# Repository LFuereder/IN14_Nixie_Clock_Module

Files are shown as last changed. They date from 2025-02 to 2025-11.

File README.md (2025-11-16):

# IN14-Nixie Tube Clock Module
This project contains the schematics, software implementation and documentation for a clock displaying the current time on nixie-tubes. The clock utilizes a GigaDevices GD32L233 microcontroller (ARM Cortex-M33), which triggers the displayed digits in the tubes via voltage-domain separation through LTV-352T optocouplers. 

The current design is planned to display hours and minutes, but it can be extended to display the seconds as well. 

The general structure of the project is as follows:
```
IN14_Nixie_Clock_Module/
|-- 01_Circuit_Board/
|-- 02_Software/
|-- 03_Datasheets/
```
In the folder `01_Circuit_Board` you can find all relevant files for the hardware part of this project. This includes the KiCAD project, footprints for the custom components and the CAD script for the custom tube socket. In folder `02_Software` you can find the implementation of the clock. As this is a module, the Board can be used as standalone application (although this does not make much sense, since you need at least two PCBs to display the current time) or as a set of two to display hour and minutes. A clock consisting of three boards is currently not supported, but can be extended in the future. Lastly in `03_Datasheets` you can find further information about the components in use. 

# Finished Prototype
The current prototype of a finished implementation of the clock is displayed in the figure below.

<p align="center">
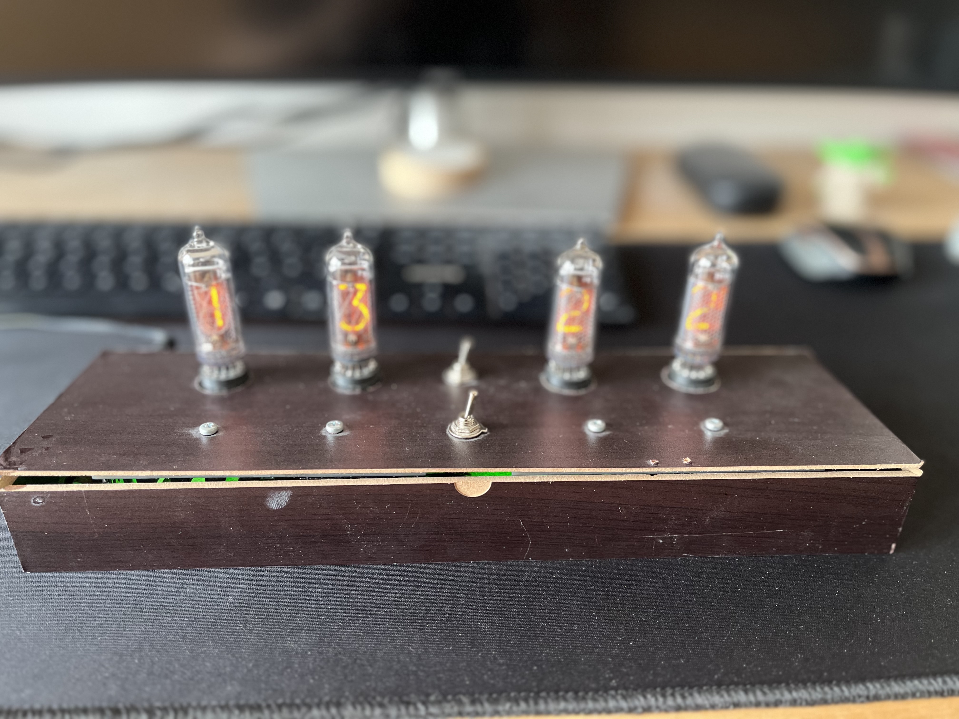
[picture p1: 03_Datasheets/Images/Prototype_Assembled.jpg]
Assembled prototype of the IN-14 nixie tube clock

</p>

For the wiring between the modules and the DCDC-converter please consider the following image:

<p align="center">
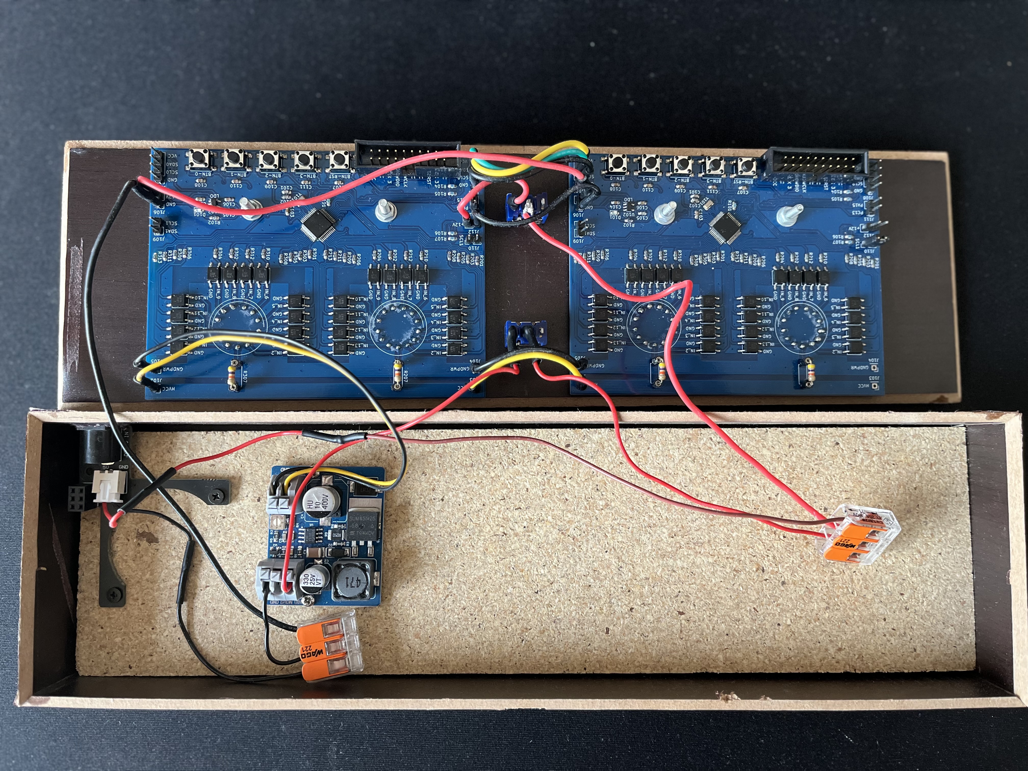
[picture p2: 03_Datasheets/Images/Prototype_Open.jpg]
Internal wiring of the IN-14 nixie tube clock prototype

</p>

Since this is a prototype, we used dupont crimp connectors and wago cage clamps. In a finished product these could be replaced by fixed/soldered wires.

# Contributing
I would like to thank [@LStromaier](https://github.com/LStrohmaier) for working along side me on this project and reviewing most of the hardware and software implemenatations.

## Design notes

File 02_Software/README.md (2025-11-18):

# Software Design
The software implementation for the nixie clock utilizes the [Firmware Library](https://www.gd32mcu.com/en/download/7?kw=GD32L2) and  SVD-file (`GD32L23x.svd`) avaiable at the GigaDevices website. Furthermore, the repository contains a simple custom linker-script (`GD32L2xx.ld`), startup code (`GD32:startup.c`) for the GD32L2xx microcontroller.

The structure of the `02_Software` folder is as follows:
```
02_Software/
|-- .vscode/
|-- CMSIS/
|-- inc/
|-- lib/
|-- src/
|-- <startup-code, linker script and SVD-file>
```
The Visual Studio Code (VS-Code) specific configuration files are located in the `.vscode` folder and currently contain the default install paths for compiler and debugger on Linux (Debian). Do feel free to adjust them to your own setup. The Gigadevices firmware library mentioned above is integrated into the project in the ARM Common Microcontroller Software Interface Standard (CMSIS) implementation in the  `CMSIS` folder and Hardware Abstraction Layer (HAL) for the GD32L2xx microcontroller in the `lib` folder. 

The implementation for the main routine and ISRs is located in the `inc` (header files) and `src` (source files) as typically done in embedded C. 

## Getting started
In order to build the code, please install the following prerequisites on your PC. Depending on the corresponding operating system, the installation method might differ from the one explained here. On Linux (Debian) execute the follwoing command in a terminal window:
```sh
sudo apt update \
sudo apt install make arm-none-eabi-gcc gdb
```

Subsequently navigate to the `02_Sofware` folder of the repository and create a build folder by executing the following command:
```sh
mkdir build
```

Lastly, build the application by typing the following command in the terminal.
```sh
make all
```

If everything works correctly, the build successful promt should appear in the terminal window.

For cleaning up or rebuilding the software, the `Makefile` also supports the commands **make new** and **make clean**. 

## Flashing and Debugging
For flashing and debugging we utilize a [J-Link](https://www.segger.com/products/debug-probes/j-link/) debug probe. The necessary software for this debugger can be downloaded from the companies website. 

In combination with the cortex-debug plugin in Visual Studio Code, we can directly flash and program the microcontroller. For further information, please refer to the `launch.json` and `c_cpp_properties.json` files in the `.vscode/` subfolder.  

## Design Concept
The software design is intended to be as simple as possible and provide the clock configuration asynchronously through interrupt service routines, while the display of the current time is managed in the main routine.

<p align="center">
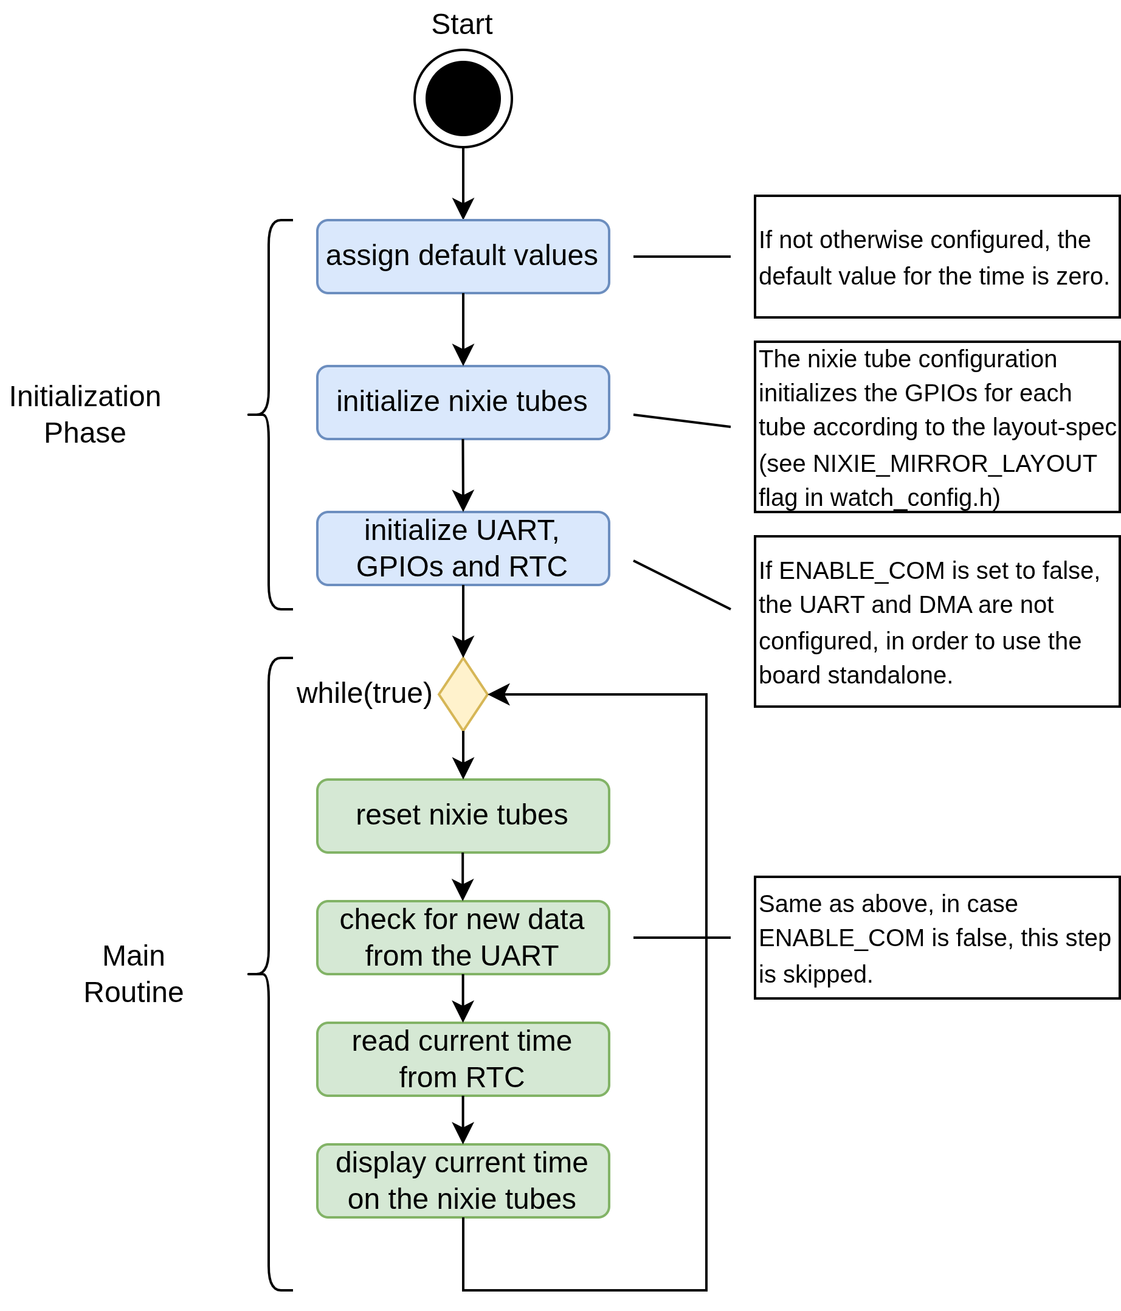
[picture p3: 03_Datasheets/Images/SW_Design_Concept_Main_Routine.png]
Internal wiring of the IN-14 nixie tube clock prototype

</p>

As displayed in the figure above, the main routine implementation first initializes all peripherals and after that periodically polls the RTC, as well as the UART implementation for new values to display. 

### Clock Configuration
Through pushing buttons BTN-3 to BTN-0, the current time can be set in the watch. The implementation for this works as follows.

<p align="center">
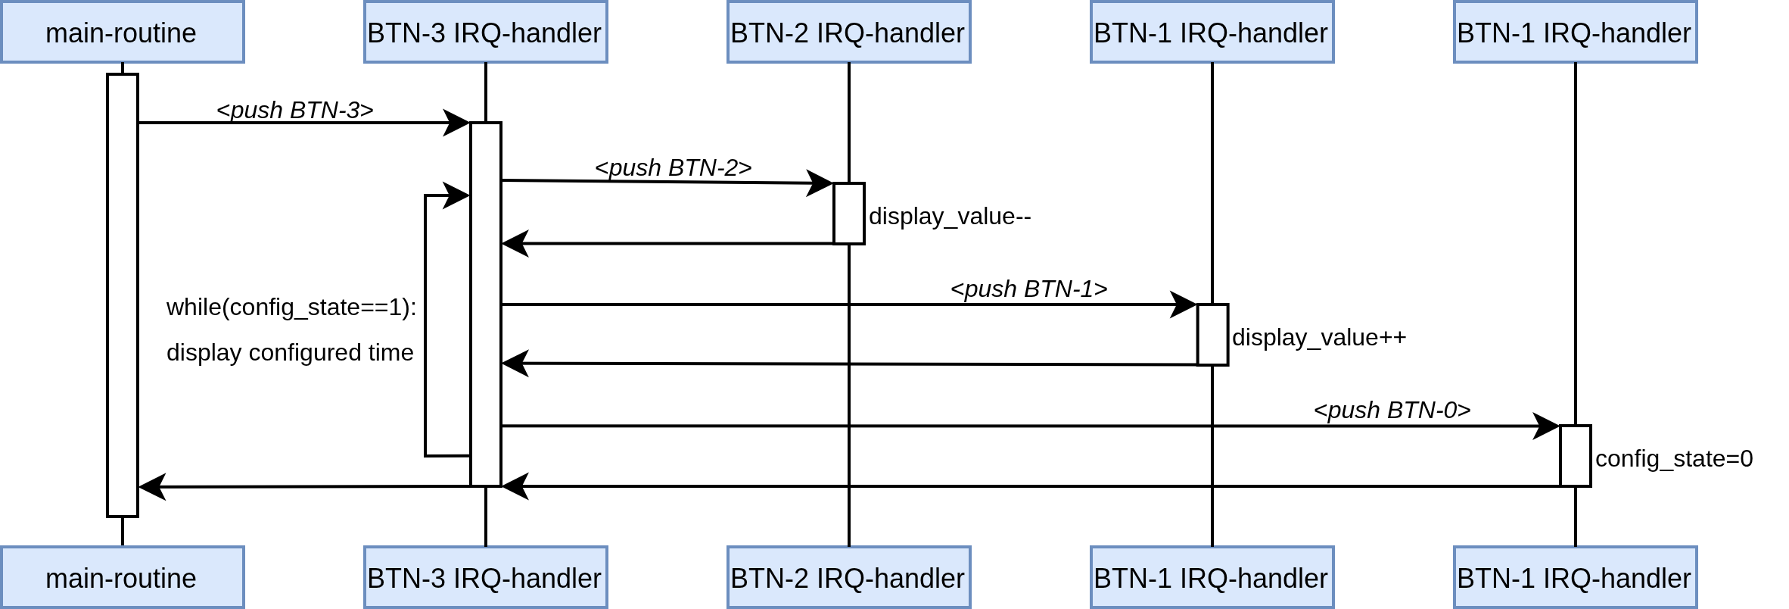
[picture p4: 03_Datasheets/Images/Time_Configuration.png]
Configuration steps for setting the time in the clock

</p>

As displayed in the figure above, the nixie-clock switches into the configuration mode by pushing button 3. In this IRQ-routine the config_state flag is set to 1 and iterates over a display of the current configuration value until button 0 is pressed to reset the config_state flag back to 0 and terminate the configuration mode. 

Buttons 2 and 3 can be used to increase or decrease the currently displayed value of the nixie-tube module. By bridging the Jumper `J111` on the PCB before start-up, the implementation can be set to display the current minutes, otherwise it displays the current hours.

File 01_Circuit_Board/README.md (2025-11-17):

# Hardware Design
The Printed Circuit Board (PCB) was designed in KiCAD as a two layer board with a separation of the voltage domain for the nixie tubes (HVCC=200V) and the board input voltage (VCC=12V). The finished PCB is displayed in the figure below:

<p align="center">
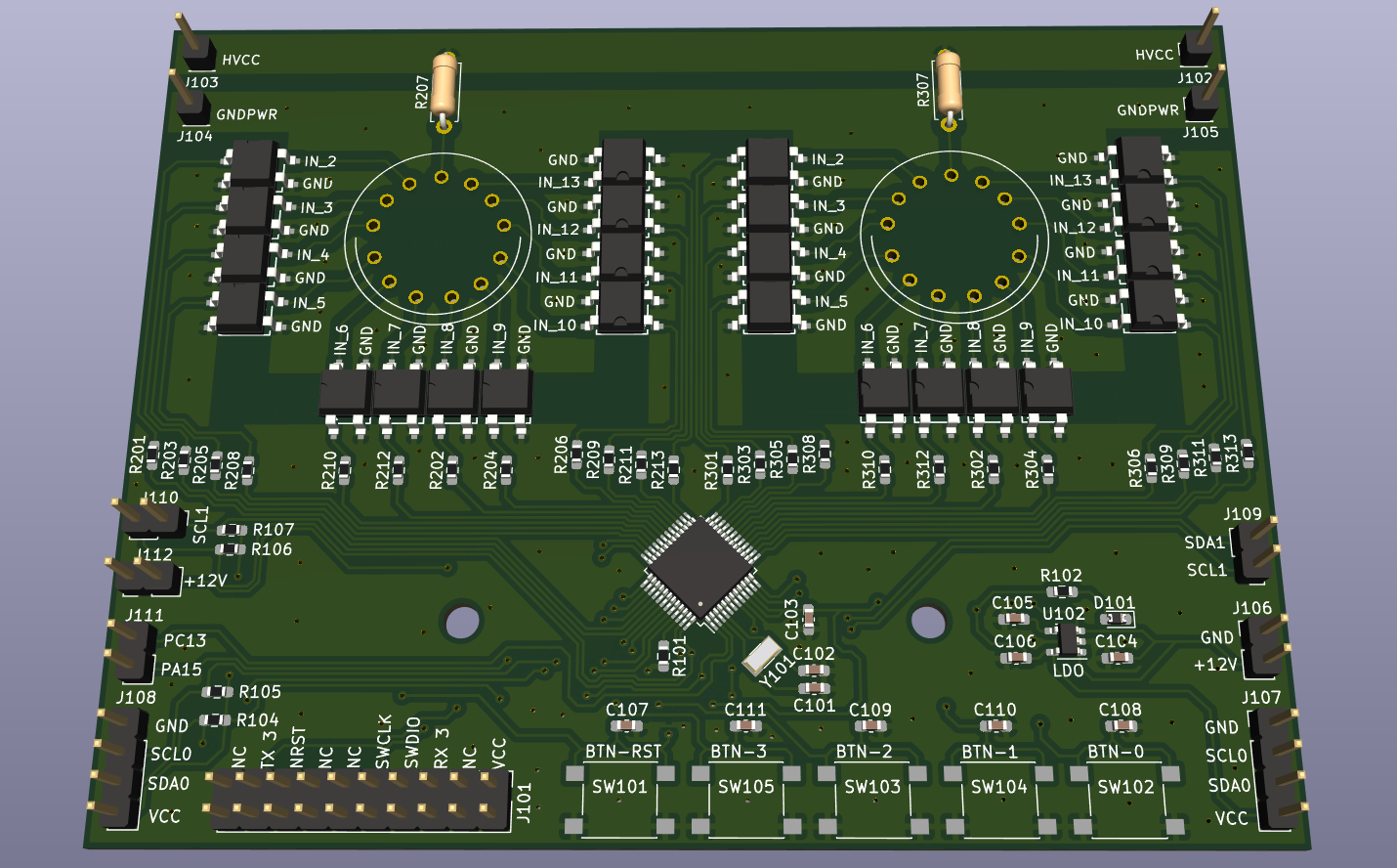
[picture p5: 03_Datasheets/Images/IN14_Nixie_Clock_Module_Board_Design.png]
Internal wiring of the IN-14 nixie tube clock prototype

</p>

Currently the power-supply is not contained in the board design and provided through an external DCDC-converter. A similar one can be used as the on sold [here](https://www.amazon.de/dp/B07H4L5NHG). 

The structure of the `01_Circuit_Board/` folder is as follows:
```
01_Circuit_Board/
    |-- bom/
    |-- footprints.pretty/
    |-- socket/
    |-- <KiCAD-Project files>
```
The following paragraphs explain briefly the content of each subfolder. 

# Componentes
In the subfolder `bom/` you can find the Bill of Materials (BOM), which contains all components and the correstponding positions on the PCB used in this project. The BOM is displayed as a simple HTML file, which you can open in your prefered web-browser simply by clicking [here](./01_Circuit_Board/bom/BOM_aurol_IN14_01.html). 

# Custom Footprints
The footprints located in the subfolder `footprints.pretty/` (default name in KiCAD) are used for the optocouplers, the custom IN-14 nixie-tube sockets. 

# Nixie-Tube Socket
In order to provide a universal socket for the IN-14 nixie-tubes, the subfolder `socket/` contains an openSCAD script, as well as the STL file for the 3D printable socket. In combination with [female connector pins](https://www.amazon.de/dp/B0C1GNPGRV) the socket can be assembled as a through-hole component, which can be soldered on the PCB.

# License
Please consider, that the entire Kicad Project is licensed unter the Apache 2.0 License

Copyright 2025 Lukas Füreder

Licensed under the Apache License, Version 2.0 (the "License");
you may not use this file except in compliance with the License.
You may obtain a copy of the License at

       http://www.apache.org/licenses/LICENSE-2.0

Unless required by applicable law or agreed to in writing, software
distributed under the License is distributed on an "AS IS" BASIS,
WITHOUT WARRANTIES OR CONDITIONS OF ANY KIND, either express or implied.
See the License for the specific language governing permissions and
limitations under the License.

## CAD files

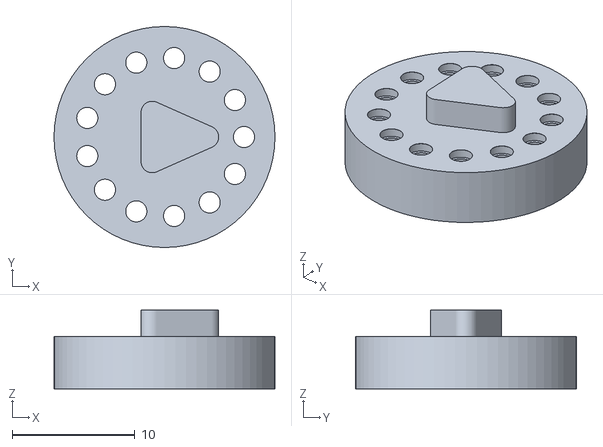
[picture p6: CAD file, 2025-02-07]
01_Circuit_Board/socket/Nixie_Socket.stl
18.0 x 18.0 x 6.42

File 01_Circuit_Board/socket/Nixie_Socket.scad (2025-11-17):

//
//  \file    Nixie_Socket.scad
//  \brief   generic tube socket of the IN14-nixie-clock module 
//
//  \version 2025-11-17, V1.0.0, IN14_NIXIE_CLOCK_MODULE
//
//
//
//
//
// Copyright 2025 Lukas Füreder
//
// Licensed under the Apache License, Version 2.0 (the "License");
// you may not use this file except in compliance with the License.
// You may obtain a copy of the License at
//
//     http://www.apache.org/licenses/LICENSE-2.0

// Unless required by applicable law or agreed to in writing, software
// distributed under the License is distributed on an "AS IS" BASIS,
// WITHOUT WARRANTIES OR CONDITIONS OF ANY KIND, either express or implied.
// See the License for the specific language governing permissions and
// limitations under the License.



$fn=64;
printWallCompensation = 0.37;


difference()
{
    union()
    {
        cylinder(h=4.28, r=9);
        keying(1.5);
    }
        
    for(i=[0 : 13])
    {
        rotate([0,0,(360-i*(360/13))])
        translate([6.477, 0, 0])
            pin_cutout();
    }
    
    scale([1.1,1.1,1.1])
        keying(0.5);
}

module pin_cutout()
{
    translate([0,0,4.28])
    #rotate([180,0,0])
    {
        cylinder(h=4.29, d=1.35+printWallCompensation, center=false);
        
        translate([0,0,0.01])
            cylinder(h=0.77, d=1.82+printWallCompensation, center=false);
    }
}

module keying(z_factor)
{
    translate([-1,0,0])
    hull()
    {
        translate([0,2,0]) 
            cylinder(h=4.28*z_factor, d=1.82);
        
        translate([0,-2,0]) 
            cylinder(h=4.28*z_factor, d=1.82);
        
        translate([4.5,0,0]) 
            cylinder(h=4.28*z_factor, d=1.82);
    }
}



//____________¶¶
//___________¶¶¶¶
//__________¶¶¶¶¶¶
//_________¶¶¥¥¥¶¶¶
//________¶¶¥¥¥¥¥¶¶¶__________________________________________¶¶¶¶¶¶¶¶
//________¶¶¥¥¥¥¥¥¶¶¶_____________________________________¶¶¶¶¶¥¥¥¥¥¶¶
//________¶¶¥¥¥¥¥¥ƒƒ¶¶________________________________¶¶¶¶¥¥¥¥¥¥¥¥¶¶¶¶
//________¶¶¥¥¥¥ƒƒƒƒƒ¶¶___________________________¶¶¶¶ƒƒ¥¥¥¥¥¥¥¥¶¶¶¶
//________¶¶¶ƒƒƒƒƒƒƒƒ§¶¶________________________¶¶ƒƒƒƒƒƒƒ¥¥¥¥¥¶¶¶¶
//_________¶¶¶ƒƒƒƒƒƒ§§¶¶____________________¶¶¶¶ƒƒƒƒƒƒƒƒƒƒ¥¥¶¶¶¶
//___________¶¶ƒƒƒƒƒ§§¶¶__________________¶¶ƒƒƒƒƒƒƒƒƒƒƒƒƒƒ¶¶¶¶
//____________¶¶ƒƒ§§§§¶¶¶¶¶¶¶¶¶¶¶¶¶¶¶¶¶¶¶¶ƒƒƒƒƒƒƒƒƒƒƒƒƒƒ§§¶¶
//_____________¶¶§§§§§§§ƒƒƒƒƒƒƒƒƒƒƒƒƒƒƒƒƒƒƒƒƒƒƒƒƒƒƒƒ§§§§¶¶
//______________¶¶§§§ƒƒƒƒƒƒƒƒƒƒƒƒƒƒƒƒƒƒƒƒƒƒƒƒƒƒ§§§§§¶¶¶¶___________________¶¶¶¶¶¶
//____________¶¶ƒƒƒƒƒƒƒƒƒƒƒƒƒƒƒƒƒƒƒƒƒƒƒƒƒƒƒƒƒƒ§§§¶¶¶____________________¶¶¶ƒƒƒƒƒ¶¶
//__________¶¶ƒƒƒƒƒƒƒƒƒƒƒƒƒƒƒƒƒƒƒƒƒ¶¶¶¶¶¶ƒƒƒƒ§§§¶¶¶___________________¶¶ƒƒƒƒƒƒƒƒ¶¶
//_________¶¶ƒƒ¶¶¶¶¶ƒƒƒƒƒƒƒƒƒƒƒƒƒƒ¶¶__¶¶¶¶ƒƒƒ§§§§§¶¶________________¶¶ƒƒƒƒƒƒƒƒƒƒ¶¶
//________¶¶ƒƒ¶¶__¶¶ƒƒƒƒƒƒƒƒƒƒƒƒƒƒ¶¶¶¶¶¶¶¶ƒƒƒ§§§§§§¶¶___________¶¶¶¶ƒƒƒƒƒƒƒƒ§§§§§§¶¶
//_______¶¶ƒƒƒ¶¶¶¶¶¶ƒƒƒƒƒƒƒƒƒƒƒƒƒƒƒ¶¶¶¶¶¶ƒƒƒƒƒ§§§§§§¶¶________¶¶ƒƒƒƒƒƒƒƒ§§§§§§§§§§¶¶
//_______¶¶ƒƒƒƒ¶¶¶¶ƒƒƒƒƒ¥¥¥ƒƒƒƒƒƒƒƒƒƒƒƒƒƒƒƒ####§§§§§¶¶____¶¶¶¶ƒƒƒƒƒƒƒƒ§§§§§§§§§§§§¶¶
//_______¶¶###ƒƒƒƒƒƒƒƒƒƒƒƒƒƒƒƒƒƒ¥¥ƒƒƒƒƒƒ########§§§§¶¶¶¶¶¶ƒƒƒƒƒƒƒƒ§§§§§§§§§§§§§§§§¶¶
//_______¶¶####ƒƒƒƒƒƒƒƒ¥¥¥¥¥¥¥¥¥¥¥ƒƒƒƒƒƒ########§§¶¶¶¶ƒƒ¶¶¶¶ƒƒƒƒ§§§§§§§§§§§§§§§§§§¶¶
//____¶¶¶¶¶¶###ƒƒƒƒƒƒƒƒƒ¥¥¥#####¥ƒƒƒƒƒƒƒ########¶¶ƒƒ¶¶ƒƒƒƒƒƒ¶¶§§§§§§§§§§§§§§§§§§§§¶¶
//__¶¶¶ƒƒ¶¶¶¶#ƒƒƒƒƒƒƒƒƒƒ¥¥####¥¥ƒƒƒƒƒƒƒƒƒƒ####§§¶¶ƒƒƒƒƒƒƒƒ¶¶¶¶§§§§§§§§§§§§§§§§¶¶¶¶
//_¶¶ƒƒ¶ƒƒƒƒ¶¶ƒƒƒƒƒƒƒƒƒƒƒƒ¥¥¥¥ƒƒƒƒƒƒƒƒƒƒƒƒƒƒ§§¶¶ƒƒƒƒƒƒƒƒƒƒƒƒ¶¶§§§§§§§§§§§§¶¶¶¶
//¶¶ƒƒƒƒƒƒ§§§§¶¶ƒƒƒƒƒƒƒƒƒƒƒƒƒƒƒƒƒƒƒƒƒƒƒƒƒƒƒƒ¶¶ƒƒƒƒƒƒƒƒ§§§§¶¶§§§§§§§§§§¶¶¶¶
//__¶¶ƒƒ§§§§§§¶¶¶¶ƒƒƒƒƒƒƒƒƒƒƒƒƒƒƒƒƒƒƒƒƒƒƒƒƒƒƒƒƒƒƒƒƒƒ§§§§§¶¶¶§§§§§§§§¶¶
//____¶¶§§§§§§§¶¶ƒƒƒƒƒƒƒƒƒƒƒƒƒƒƒƒƒƒƒƒƒƒƒƒƒƒƒƒƒƒƒƒƒ§§§§§§¶__¶§§§§§§¶¶
//______¶¶§§§§§§ƒƒƒƒƒƒƒƒƒƒƒƒƒƒƒƒƒƒƒƒƒƒƒƒƒƒƒƒƒƒƒƒ§§§§§§¶¶____¶¶§§§§§§¶¶
//________¶¶¶§ƒƒƒƒƒƒƒƒƒƒƒƒƒƒƒƒƒƒƒƒƒƒƒƒƒƒƒƒƒƒƒƒƒ§§§§§§¶¶_______¶¶§§§§§§¶¶
//_________¶¶ƒƒƒƒƒƒƒƒƒƒƒƒƒƒƒƒƒƒƒƒƒƒƒƒƒƒƒƒƒƒƒƒƒ§§§§¶¶¶¶____¶¶¶¶§§§§§§§§§§¶¶
//_________¶¶ƒƒƒƒƒƒƒƒƒƒƒƒƒƒƒƒƒƒƒƒƒƒƒƒƒƒƒƒƒƒƒƒƒ§§¶¶§§¶¶¶¶¶¶ƒƒ§§§§§§§§¶¶¶¶
//________¶¶ƒƒƒƒƒƒƒƒƒƒƒƒƒƒƒƒƒƒƒƒƒƒƒƒƒƒƒƒƒƒƒƒƒ§§§§§§§¶¶ƒƒƒƒ§§§§§§¶¶¶¶
//________¶¶ƒƒƒƒƒƒƒƒƒƒƒƒƒƒƒƒƒƒƒƒƒƒƒƒƒƒƒƒƒƒƒ§§§§§§§§¶¶§§§§§§§¶¶¶¶
//__¶¶¶¶¶¶¶¶¶ƒƒƒƒƒƒƒƒƒƒƒƒƒƒƒƒƒƒƒƒƒƒƒƒƒƒƒƒ§§§§§§§§§¶¶§§§§§§¶¶
//_¶¶ƒƒ¶¶ƒƒƒ¶¶ƒƒƒƒƒƒƒƒƒƒƒƒƒƒƒƒƒƒƒƒƒƒƒƒƒƒƒ§§§§§§§§§¶¶¶¶§§§§§§¶¶
//_¶¶ƒƒƒ¶¶ƒƒƒ¶¶ƒƒƒƒƒƒƒƒƒƒƒƒƒƒƒƒƒƒƒƒƒƒƒƒ§§§§§§§§§§¶¶__¶¶¶###§§§¶¶
//__¶¶§§§§§§§§¶¶ƒƒƒƒƒƒƒƒƒƒƒƒƒƒƒƒƒƒƒƒ§§§§§§§§§§§§§¶¶¶¶¶#######§§§¶¶
//___¶¶§§§§§§§§¶¶ƒƒƒƒƒƒƒƒƒƒƒƒƒƒƒƒ§§§§§§§§§§§§§§§§§########¶¶¶¶¶¶
//____¶¶§§§§§§§§¶¶§§§§ƒƒƒƒƒƒƒ§§§§§§§§§§§§§§§§§§§####¶¶¶¶¶¶
//_____¶¶§§§§§§§¶¶§§§§§§§§§§§§§§§§§§§§§§§§§§§§§§¶¶¶¶
//_______¶¶¶¶¶¶¶§§§§§§§§§§§§§§§§§§§§§§§§§§§§§§§§¶¶
//______________¶¶¶¶¶¶¶¶¶¶§§§§§§§§§§§§§§§§§§§§¶¶
//________________________¶¶¶¶¶¶§§§§§§§§§§¶¶¶¶
//____________________________¶¶¶¶§§§§¶¶¶¶¶
//____________________________¶¶§§§§§§§§¶¶
//____________________________¶¶§§¶¶§§§¶¶
//_____________________________¶¶§¶¶§§¶¶
//______________________________¶¶¶¶¶¶ 

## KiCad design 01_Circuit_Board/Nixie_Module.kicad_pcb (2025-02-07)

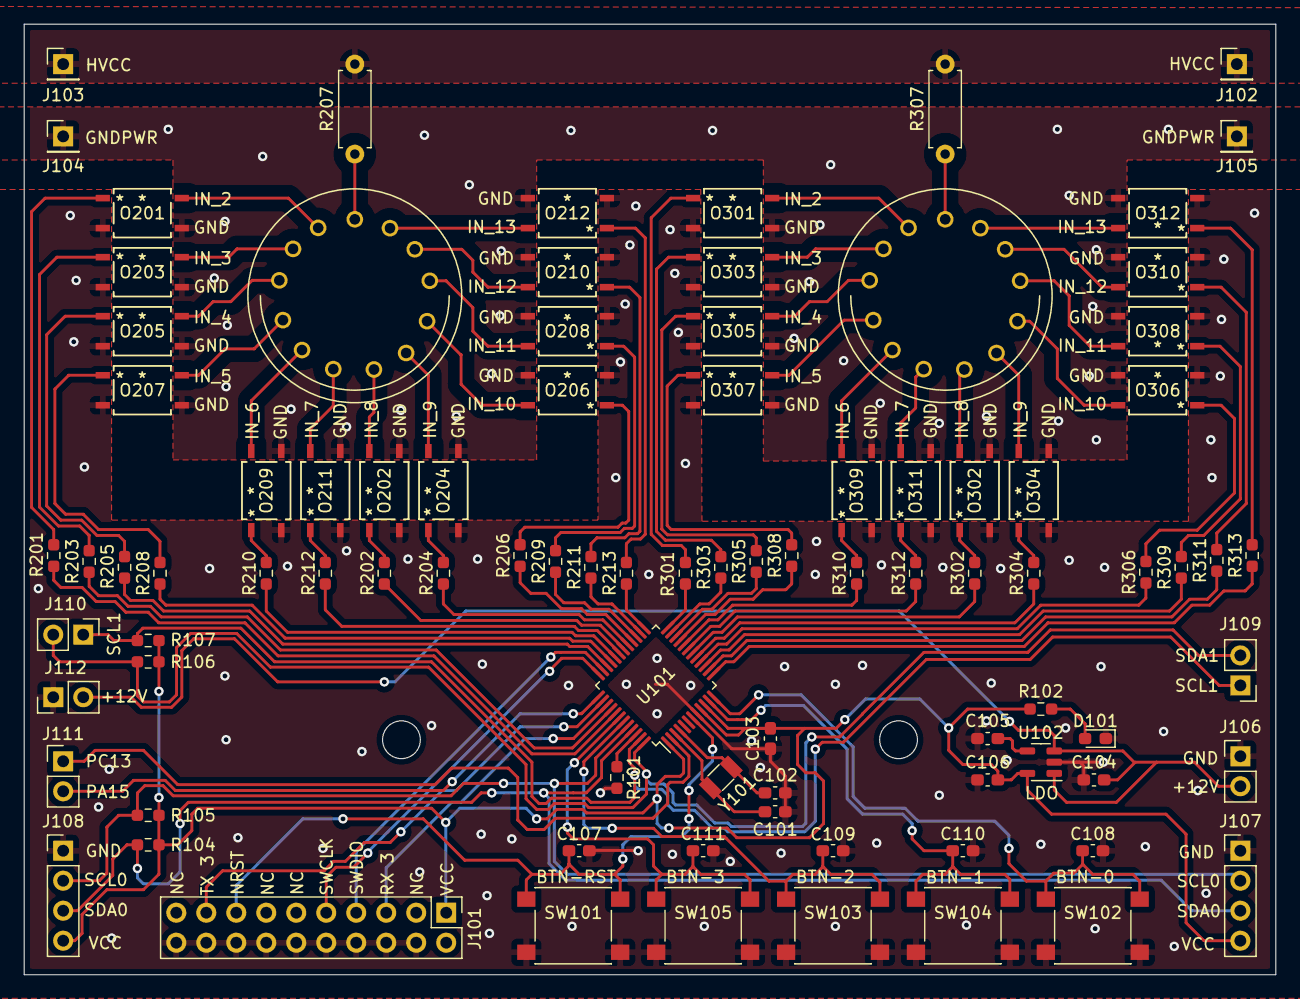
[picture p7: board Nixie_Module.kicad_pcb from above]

Board: 2 copper layers, 106.0 x 80.5 mm, 90 parts (0 on the bottom side), 99 nets.

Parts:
C101, C102, C103, C104, C106, C107, C108, C109, C110, C111: 1u; C_0603_1608Metric_Pad1.08x0.95mm_HandSolder
C105: 470p; C_0603_1608Metric_Pad1.08x0.95mm_HandSolder
D101: LED; D_0603_1608Metric_Pad1.05x0.95mm_HandSolder
J101: JTAG_CON; PinHeader_2x10_P2.54mm_Vertical
J102: HV-IN; PinHeader_1x01_P2.54mm_Vertical
J103: HV-OUT; PinHeader_1x01_P2.54mm_Vertical
J104: HVGND-OUT; PinHeader_1x01_P2.54mm_Vertical
J105: HVGND-IN; PinHeader_1x01_P2.54mm_Vertical
J106: 12V-OUT; PinHeader_1x02_P2.54mm_Vertical
J107: Prime-CON-IN; PinHeader_1x04_P2.54mm_Vertical
J108: Prime-CON-OUT; PinHeader_1x04_P2.54mm_Vertical
J109: Sec-CON-IN; PinHeader_1x02_P2.54mm_Vertical
J110: Sec-CON-OUT; PinHeader_1x02_P2.54mm_Vertical
J111: GPIO_Con; PinHeader_1x02_P2.54mm_Vertical
J112: 12V-IN; PinHeader_1x02_P2.54mm_Vertical
O201, O202, O203, O204, O205, O206, O207, O208, O209, O210, O211, O212, O301, O302, O303, O304, O305, O306, O307, O308, O309, O310, O311, O312: LTV-352T; IC4_LTV-352T_LTO
R101, R104, R105, R106, R107: 5k6R; R_0603_1608Metric_Pad0.98x0.95mm_HandSolder
R102: 300R; R_0603_1608Metric_Pad0.98x0.95mm_HandSolder
R201, R202, R203, R204, R205, R206, R208, R209, R210, R211, R212, R213, R301, R302, R303, R304, R305, R306, R308, R309, R310, R311, R312, R313: 154R; R_0603_1608Metric_Pad0.98x0.95mm_HandSolder
R207, R307: 69kR; R_Axial_DIN0207_L6.3mm_D2.5mm_P7.62mm_Horizontal
SW101: RST-BTN; SW_Push_1P1T_NO_6x6mm_H9.5mm
SW102: BTN0; SW_Push_1P1T_NO_6x6mm_H9.5mm
SW103: BTN2; SW_Push_1P1T_NO_6x6mm_H9.5mm
SW104: BTN1; SW_Push_1P1T_NO_6x6mm_H9.5mm
SW105: BTN3; SW_Push_1P1T_NO_6x6mm_H9.5mm
TBE201, TBE301: IN14; IN-14_Nixie
U101: LQFP-48_7x7mm_P0.5mm
U102: MIC5219-3.3YM5; SOT-23-5
Y101: Crystal; Crystal_SMD_3215-2Pin_3.2x1.5mm

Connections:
+3.3V: C103.2, C106.1, J101.1 (VTREF), J107.4, J108.4, R102.2, R104.1, R105.2, R106.1, R107.2, U101.1 (VBAT), U101.9 (VREFP), U101.10 (VDD), U102.5 (OUT)
+12V: C104.1, J106.2, J112.2, U102.1 (IN), U102.3 (EN)
/1_OC_1: R201.1, U101.41 (PB3)
/1_OC_2: R203.1, U101.40 (PC12)
/1_OC_3: R205.1, U101.34 (PA12)
/1_OC_4: R208.1, U101.33 (PA11)
/1_OC_5: R210.1, U101.32 (PA10)
/1_OC_6: R212.1, U101.31 (PA9)
/1_OC_7: R202.1, U101.30 (PA8)
/1_OC_8: R204.1, U101.29 (PC7)
/1_OC_9: R206.1, U101.28 (PC6)
/1_OC_10: R209.1, U101.27 (PB15)
/1_OC_11: R211.1, U101.26 (PB14)
/1_OC_12: R213.1, U101.25 (PB13)
/2_OC_1: R301.1, U101.24 (PB12)
/2_OC_2: R303.1, U101.23 (PB11)
/2_OC_3: R305.1, U101.22 (PB10)
/2_OC_4: R308.1, U101.21 (BOOT1-PB2)
/2_OC_5: R310.1, U101.20 (PB1)
/2_OC_6: R312.1, U101.19 (PB0)
/2_OC_7: R302.1, U101.18 (PA7)
/2_OC_8: R304.1, U101.17 (PA6)
/2_OC_9: R306.1, U101.16 (PA5)
/2_OC_10: R309.1, U101.15 (PA4)
/2_OC_11: R311.1, U101.14 (PA3)
/2_OC_12: R313.1, U101.13 (PA2)
/BOOT0: R101.1, U101.46 (BOOT0-PD3)
/BTN0: C108.1, SW102.1, U101.12 (PA1)
/BTN1: C110.1, SW104.1, U101.11 (PA0)
/BTN2: C109.1, SW103.1, U101.43 (PB5)
/BTN3: C111.1, SW105.1, U101.42 (PB4)
/IN14_1/1_IN14_2: O201.4, TBE201.2 (.Comma)
/IN14_1/1_IN14_3: O203.4, TBE201.3 (C1)
/IN14_1/1_IN14_4: O205.4, TBE201.4 (C2)
/IN14_1/1_IN14_5: O207.4, TBE201.5 (C3)
/IN14_1/1_IN14_6: O209.4, TBE201.6 (C4)
/IN14_1/1_IN14_7: O211.4, TBE201.7 (C5)
/IN14_1/1_IN14_8: O202.4, TBE201.8 (C6)
/IN14_1/1_IN14_9: O204.4, TBE201.9 (C7)
/IN14_1/1_IN14_10: O206.4, TBE201.10 (C8)
/IN14_1/1_IN14_11: O208.4, TBE201.11 (C9)
/IN14_1/1_IN14_12: O210.4, TBE201.12 (C0)
/IN14_1/1_IN14_13: O212.4, TBE201.13 (Comma.)
/IN14_2/2_IN14_2: O301.4, TBE301.2 (.Comma)
/IN14_2/2_IN14_3: O303.4, TBE301.3 (C1)
/IN14_2/2_IN14_4: O305.4, TBE301.4 (C2)
/IN14_2/2_IN14_5: O307.4, TBE301.5 (C3)
/IN14_2/2_IN14_6: O309.4, TBE301.6 (C4)
/IN14_2/2_IN14_7: O311.4, TBE301.7 (C5)
/IN14_2/2_IN14_8: O302.4, TBE301.8 (C6)
/IN14_2/2_IN14_9: O304.4, TBE301.9 (C7)
/IN14_2/2_IN14_10: O306.4, TBE301.10 (C8)
/IN14_2/2_IN14_11: O308.4, TBE301.11 (C9)
/IN14_2/2_IN14_12: O310.4, TBE301.12 (C0)
/IN14_2/2_IN14_13: O312.4, TBE301.13 (Comma.)
/NRST: C107.1, J101.15 (~SRST), SW101.1, U101.7 (NRST)
/PA15: J111.2, U101.37 (PA15)
/PC13: J111.1, U101.2 (PC13)
/SCL0/UART0_TX: J107.2, J108.2, R105.1, U101.44 (PB6)
/SCL1: J109.1, J110.1, R107.1, U101.47 (PB8)
/SDA0/UART0_RX: J107.3, J108.3, R104.2, U101.45 (PB7)
/SDA1: J109.2, J110.2, R106.2, U101.48 (PB9)
/SWCLK: J101.9 (TCK/SWDCLK), U101.36 (PA14)
/SWDIO: J101.7 (TMS/SWDIO), U101.35 (PA13)
/UART3_RX: J101.5 (TDI/UART-Tx), U101.39 (PC11)
/UART3_TX: J101.17 (DBGRQ/UART-Rx), U101.38 (PC10)
GND: C101.2, C102.2, C103.1, C104.2, C105.2, C106.2, C107.2, C108.2, C109.2, C110.2, C111.2, D101.1 (K), J101.4 (GND), J101.6 (GND), J101.8 (GND), J101.10 (GND), J101.12 (GND), J101.14 (GND), J101.16 (GND), J101.18 (GND), J101.20 (GND), J106.1, J107.1, J108.1, J112.1, O201.2, O202.2, O203.2, O204.2, O205.2, O206.2, O207.2, O208.2, O209.2, O210.2, O211.2, O212.2, O301.2, O302.2, O303.2, O304.2, O305.2, O306.2, O307.2, O308.2, O309.2, O310.2, O311.2, O312.2, R101.2, SW101.2, SW102.2, SW103.2, SW104.2, SW105.2, U101.8 (VSS), U102.2 (GND)
GNDPWR: J104.1, J105.1, O201.3, O202.3, O203.3, O204.3, O205.3, O206.3, O207.3, O208.3, O209.3, O210.3, O211.3, O212.3, O301.3, O302.3, O303.3, O304.3, O305.3, O306.3, O307.3, O308.3, O309.3, O310.3, O311.3, O312.3
HVCC: J102.1, J103.1, R207.2, R307.2
unnamed: D101.2 (A), R102.1
unnamed: O201.1, R201.2
unnamed: O202.1, R202.2
unnamed: O203.1, R203.2
unnamed: O204.1, R204.2
unnamed: O205.1, R205.2
unnamed: O206.1, R206.2
unnamed: O207.1, R208.2
unnamed: O208.1, R209.2
unnamed: O209.1, R210.2
unnamed: O210.1, R211.2
unnamed: O211.1, R212.2
unnamed: O212.1, R213.2
unnamed: O301.1, R301.2
unnamed: O302.1, R302.2
unnamed: O303.1, R303.2
unnamed: O304.1, R304.2
unnamed: O305.1, R305.2
unnamed: O306.1, R306.2
unnamed: O307.1, R308.2
unnamed: O308.1, R309.2
unnamed: O309.1, R310.2
unnamed: O310.1, R311.2
unnamed: O311.1, R312.2
unnamed: O312.1, R313.2
unnamed: R207.1, TBE201.1 (Anode)
unnamed: R307.1, TBE301.1 (Anode)
unnamed: C101.1, U101.3 (PC14), Y101.1
unnamed: C102.1, U101.4 (PC15), Y101.2
unnamed: C105.1, U102.4 (BP)

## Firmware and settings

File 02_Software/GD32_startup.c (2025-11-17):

/*!
    \file    GD32_startup.c
    \brief   startup code of the IN14-nixie-clock module 

    \version 2025-11-17, V1.0.0, IN14_NIXIE_CLOCK_MODULE
*/

/*

/*
   Copyright 2025 Lukas Füreder

   Licensed under the Apache License, Version 2.0 (the "License");
   you may not use this file except in compliance with the License.
   You may obtain a copy of the License at

       http://www.apache.org/licenses/LICENSE-2.0

   Unless required by applicable law or agreed to in writing, software
   distributed under the License is distributed on an "AS IS" BASIS,
   WITHOUT WARRANTIES OR CONDITIONS OF ANY KIND, either express or implied.
   See the License for the specific language governing permissions and
   limitations under the License.
*/


#ifndef int16_t
    typedef short int                   int16_t;
#endif
#ifndef int32_t
    typedef int                         int32_t;
#endif
#ifndef int8_t
    typedef signed char                 int8_t;
#endif
#ifndef uint8_t
    typedef unsigned char               uint8_t;
#endif
#ifndef uint16_t
    typedef unsigned short int          uint16_t;
#endif
#ifndef uint32_t
    typedef unsigned int                uint32_t;
#endif
#ifndef bool 
    typedef enum {false, true} bool;
#endif

#define RAM_START 0x20000000
#define RAM_SIZE 0x8000



#define RAM_END ((RAM_START)+(RAM_SIZE))
#define STACK_START RAM_END

extern uint32_t _etext;
extern uint32_t _edata;
extern uint32_t _sdata;
extern uint32_t _ebss;
extern uint32_t _sbss;

extern void SystemInit(void);
extern int main(void);

void RESET_HANDLER(void);

    void NMI_HANDLER(void)          __attribute__((weak, alias("DEFAULT_HANDLER")));               
    void HardFault_HANDLER(void)    __attribute__((weak, alias("DEFAULT_HANDLER")));         
    void SVC_HANDLER(void)          __attribute__((weak, alias("DEFAULT_HANDLER")));               
    void PendSV_HANDLER(void)       __attribute__((weak, alias("DEFAULT_HANDLER")));            
    void SysTick_HANDLER(void)      __attribute__((weak, alias("DEFAULT_HANDLER")));           
    void WDT_HANDLER(void)          __attribute__((weak, alias("DEFAULT_HANDLER")));               
    void LVD_HANDLER(void)          __attribute__((weak, alias("DEFAULT_HANDLER")));               
    void RTC_TAMPER_HANDLER(void)   __attribute__((weak, alias("DEFAULT_HANDLER")));        
    void RTC_WAKE_HANDLER(void)     __attribute__((weak, alias("DEFAULT_HANDLER")));          
    void FMC_HANDLER(void)          __attribute__((weak, alias("DEFAULT_HANDLER")));               
    void RCU_CTC_HANDLER(void)      __attribute__((weak, alias("DEFAULT_HANDLER")));           
    void EXTI0_HANDLER(void)        __attribute__((weak, alias("DEFAULT_HANDLER")));             
    void EXTI1_HANDLER(void)        __attribute__((weak, alias("DEFAULT_HANDLER")));             
    void EXTI2_HANDLER(void)        __attribute__((weak, alias("DEFAULT_HANDLER")));             
    void EXTI3_HANDLER(void)        __attribute__((weak, alias("DEFAULT_HANDLER")));             
    void EXTI4_HANDLER(void)        __attribute__((weak, alias("DEFAULT_HANDLER")));             
    void DMA0_HANDLER(void)         __attribute__((weak, alias("DEFAULT_HANDLER")));              
    void DMA1_HANDLER(void)         __attribute__((weak, alias("DEFAULT_HANDLER")));              
    void DMA2_HANDLER(void)         __attribute__((weak, alias("DEFAULT_HANDLER")));              
    void DMA3_HANDLER(void)         __attribute__((weak, alias("DEFAULT_HANDLER")));              
    void DMA4_HANDLER(void)         __attribute__((weak, alias("DEFAULT_HANDLER")));              
    void DMA5_HANDLER(void)         __attribute__((weak, alias("DEFAULT_HANDLER")));              
    void DMA6_HANDLER(void)         __attribute__((weak, alias("DEFAULT_HANDLER")));              
    void ADC_HANDLER(void)          __attribute__((weak, alias("DEFAULT_HANDLER")));               
    void USBD_HIGH_HANDLER(void)    __attribute__((weak, alias("DEFAULT_HANDLER")));         
    void USBD_LOW_HANDLER(void)     __attribute__((weak, alias("DEFAULT_HANDLER")));          
    void TIM1_HANDLER(void)         __attribute__((weak, alias("DEFAULT_HANDLER")));              
    void TIM2_HANDLER(void)         __attribute__((weak, alias("DEFAULT_HANDLER")));              
    void TIM8_HANDLER(void)         __attribute__((weak, alias("DEFAULT_HANDLER")));              
    void TIM11_HANDLER(void)        __attribute__((weak, alias("DEFAULT_HANDLER")));             
    void TIM5_HANDLER(void)         __attribute__((weak, alias("DEFAULT_HANDLER")));              
    void TIM6_HANDLER(void)         __attribute__((weak, alias("DEFAULT_HANDLER")));              
    void USART0_HANDLER(void)       __attribute__((weak, alias("DEFAULT_HANDLER")));            
    void USART1_HANDLER(void)       __attribute__((weak, alias("DEFAULT_HANDLER")));            
    void UART3_HANDLER(void)        __attribute__((weak, alias("DEFAULT_HANDLER")));             
    void UART4_HANDLER(void)        __attribute__((weak, alias("DEFAULT_HANDLER")));             
    void I2C0_EVENT_HANDLER(void)   __attribute__((weak, alias("DEFAULT_HANDLER")));        
    void I2C0_ERROR_HANDLER(void)   __attribute__((weak, alias("DEFAULT_HANDLER")));        
    void I2C1_EVENT_HANDLER(void)   __attribute__((weak, alias("DEFAULT_HANDLER")));        
    void I2C1_ERROR_HANDLER(void)   __attribute__((weak, alias("DEFAULT_HANDLER")));        
    void SPI0_HANDLER(void)         __attribute__((weak, alias("DEFAULT_HANDLER")));              
    void SPI1_HANDLER(void)         __attribute__((weak, alias("DEFAULT_HANDLER")));              
    void DAC_HANDLER(void)          __attribute__((weak, alias("DEFAULT_HANDLER")));               
    void I2C2_EVENT_HANDLER(void)   __attribute__((weak, alias("DEFAULT_HANDLER")));        
    void I2C2_ERROR_HANDLER(void)   __attribute__((weak, alias("DEFAULT_HANDLER")));        
    void RTC_ALARM_HANDLER(void)    __attribute__((weak, alias("DEFAULT_HANDLER")));         
    void USBD_WAKE_HANDLER(void)    __attribute__((weak, alias("DEFAULT_HANDLER")));         
    void EXTI5_to_9_HANDLER(void)   __attribute__((weak, alias("DEFAULT_HANDLER")));        
    void EXTI10_to_15_HANDLER(void) __attribute__((weak, alias("DEFAULT_HANDLER")));      
    void DMA_MUX_HANDLER(void)      __attribute__((weak, alias("DEFAULT_HANDLER")));           
    void CMP0_OUT_HANDLER(void)     __attribute__((weak, alias("DEFAULT_HANDLER")));          
    void CMP1_OUT_HANDLER(void)     __attribute__((weak, alias("DEFAULT_HANDLER")));          
    void I2C0_WAKE_HANDLER(void)    __attribute__((weak, alias("DEFAULT_HANDLER")));         
    void I2C2_WAKE_HANDLER(void)    __attribute__((weak, alias("DEFAULT_HANDLER")));         
    void USART0_WAKE_HANDLER(void)  __attribute__((weak, alias("DEFAULT_HANDLER")));       
    void LPUART_HANDLER(void)       __attribute__((weak, alias("DEFAULT_HANDLER")));            
    void CAU_HANDLER(void)          __attribute__((weak, alias("DEFAULT_HANDLER")));               
    void TRNG_HANDLER(void)         __attribute__((weak, alias("DEFAULT_HANDLER")));              
    void SLCD_HANDLER(void)         __attribute__((weak, alias("DEFAULT_HANDLER")));              
    void USART1_WAKE_HANDLER(void)  __attribute__((weak, alias("DEFAULT_HANDLER")));       
    void I2C1_WAKE_HANDLER(void)    __attribute__((weak, alias("DEFAULT_HANDLER")));         
    void LPUART_WAKE_HANDLER(void)  __attribute__((weak, alias("DEFAULT_HANDLER")));       
    void LPTIMER_HANDLER(void)      __attribute__((weak, alias("DEFAULT_HANDLER")));           

//##//

uint32_t vectors[] __attribute__((section(".isr_vector"))) =
{
    STACK_START,                            // 0
    (uint32_t)&RESET_HANDLER,               // 1
    (uint32_t)&NMI_HANDLER,                 // 2
    (uint32_t)&HardFault_HANDLER,           // 3
    0,                                      // 4
    0,                                      // 5
    0,                                      // 6
    0,                                      // 7
    0,                                      // 8
    0,                                      // 9
    0,                                      //10
    (uint32_t)&SVC_HANDLER,                 //11
    0,                                      //12
    0,                                      //13
    (uint32_t)&PendSV_HANDLER,              //14
    (uint32_t)&SysTick_HANDLER,             //15
    (uint32_t)&WDT_HANDLER,                 //16
    (uint32_t)&LVD_HANDLER,                 //17
    (uint32_t)&RTC_TAMPER_HANDLER,          //18
    (uint32_t)&RTC_WAKE_HANDLER,            //19
    (uint32_t)&FMC_HANDLER,                 //20
    (uint32_t)&RCU_CTC_HANDLER,             //21
    (uint32_t)&EXTI0_HANDLER,               //22
    (uint32_t)&EXTI1_HANDLER,               //23
    (uint32_t)&EXTI2_HANDLER,               //24
    (uint32_t)&EXTI3_HANDLER,               //25
    (uint32_t)&EXTI4_HANDLER,               //26
    (uint32_t)&DMA0_HANDLER,                //27
    (uint32_t)&DMA1_HANDLER,                //28
    (uint32_t)&DMA2_HANDLER,                //29
    (uint32_t)&DMA3_HANDLER,                //30
    (uint32_t)&DMA4_HANDLER,                //31
    (uint32_t)&DMA5_HANDLER,                //32
    (uint32_t)&DMA6_HANDLER,                //33
    (uint32_t)&ADC_HANDLER,                 //34
    (uint32_t)&USBD_HIGH_HANDLER,           //35
    (uint32_t)&USBD_LOW_HANDLER,            //36
    (uint32_t)&TIM1_HANDLER,                //37
    (uint32_t)&TIM2_HANDLER,                //38
    (uint32_t)&TIM8_HANDLER,                //39
    (uint32_t)&TIM11_HANDLER,               //40
    (uint32_t)&TIM5_HANDLER,                //41
    (uint32_t)&TIM6_HANDLER,                //42
    (uint32_t)&USART0_HANDLER,              //43
    (uint32_t)&USART1_HANDLER,              //44
    (uint32_t)&UART3_HANDLER,               //45
    (uint32_t)&UART4_HANDLER,               //46
    (uint32_t)&I2C0_EVENT_HANDLER,          //47
    (uint32_t)&I2C0_ERROR_HANDLER,          //48
    (uint32_t)&I2C1_EVENT_HANDLER,          //49
    (uint32_t)&I2C1_ERROR_HANDLER,          //50
    (uint32_t)&SPI0_HANDLER,                //51
    (uint32_t)&SPI1_HANDLER,                //52
    (uint32_t)&DAC_HANDLER,                 //53
    0,                                      //54
    (uint32_t)&I2C2_EVENT_HANDLER,          //55
    (uint32_t)&I2C2_ERROR_HANDLER,          //56
    (uint32_t)&RTC_ALARM_HANDLER,           //57
    (uint32_t)&USBD_WAKE_HANDLER,           //58
    (uint32_t)&EXTI5_to_9_HANDLER,          //59
    0,                                      //60
    0,                                      //61
    (uint32_t)&EXTI10_to_15_HANDLER,        //63
    0,                                      //64
    0,                                      //65
    0,                                      //66
    0,                                      //67
    0,                                      //68
    0,                                      //69
    0,                                      //70
    (uint32_t)&DMA_MUX_HANDLER,             //71
    (uint32_t)&CMP0_OUT_HANDLER,            //72
    (uint32_t)&CMP1_OUT_HANDLER,            //73
    (uint32_t)&I2C0_WAKE_HANDLER,           //74
    (uint32_t)&I2C2_WAKE_HANDLER,           //75
    (uint32_t)&USART0_WAKE_HANDLER,         //76
    (uint32_t)&LPUART_HANDLER,              //77
    (uint32_t)&CAU_HANDLER,                 //78
    (uint32_t)&TRNG_HANDLER,                //79
    (uint32_t)&SLCD_HANDLER,                //80
    (uint32_t)&USART1_WAKE_HANDLER,         //81
    (uint32_t)&I2C1_WAKE_HANDLER,           //82
    (uint32_t)&LPUART_WAKE_HANDLER,         //83
    (uint32_t)&LPTIMER_HANDLER,             //84
};

void DEFAULT_HANDLER(void)
{
    while(true)
    {
        __asm("nop");
    }
}
void RESET_HANDLER(void)
{
    uint32_t size = &_edata - &_sdata;
    uint32_t *pDest = (uint32_t*)&_sdata;
    uint32_t *pSrc= (uint32_t*)&_etext;
    for(uint32_t i =0;i<size;i++)
    {
        *pDest++=*pSrc++;
    }
    //init bss
    size = &_ebss - &_sbss;
    pDest = (uint32_t*)&_sbss;
    for(uint32_t i =0;i<size;i++)
    {
        *pDest++=0;
    }

    SystemInit();
    //call main
    main();
}

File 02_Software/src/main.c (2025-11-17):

/*!
    \file    main.c
    \brief   Entry-point of the IN14-nixie-clock module 

    \version 2025-11-17, V1.0.0, IN14_NIXIE_CLOCK_MODULE
*/

/*

/*
   Copyright 2025 Lukas Füreder

   Licensed under the Apache License, Version 2.0 (the "License");
   you may not use this file except in compliance with the License.
   You may obtain a copy of the License at

       http://www.apache.org/licenses/LICENSE-2.0

   Unless required by applicable law or agreed to in writing, software
   distributed under the License is distributed on an "AS IS" BASIS,
   WITHOUT WARRANTIES OR CONDITIONS OF ANY KIND, either express or implied.
   See the License for the specific language governing permissions and
   limitations under the License.
*/


#include "../inc/main.h"

/* Global object containing the current time */
rtc_parameter_struct current_time;

/* Global variable for clock configuration */
uint8_t config_state = 0;

/* Nixie-Clock position and status flag */
bool show_minutes = false;


#if ENABLE_COM
/* In case communication with another controller
   is enabled, this function checks for available 
   data in the UART0 buffer. */
void check_for_new_timeValues()
{
        if(show_minutes)
        {
            if(update_current_time(&current_time.hour))
            {
                init_RTC(current_time);
            }
        }
        else
        {
            if(update_current_time(&current_time.minute))
            {
                init_RTC(current_time);
            }
        }
}
#endif

/* This application checks, which time value to 
   to display by checking, if the PA15/PC13 
   jumber is bridged. If so, the PCB displays the 
   the current hour, otherwise it displays the 
   current minute of time. */
void get_clk_position(bool* show_minutes)
{
    gpio_mode_set(GPIOC, GPIO_MODE_OUTPUT, GPIO_PUPD_NONE, GPIO_PIN_13);
    gpio_output_options_set(GPIOC, GPIO_OTYPE_PP, GPIO_OSPEED_2MHZ, GPIO_PIN_13);
    gpio_bit_set(GPIOC, GPIO_PIN_13);

    gpio_mode_set(GPIOA, GPIO_MODE_INPUT, GPIO_PUPD_NONE, GPIO_PIN_15);
    
    if(gpio_input_bit_get(GPIOA, GPIO_PIN_15) == SET)
    {
        *show_minutes = false;
    }
    else
    {
        *show_minutes = true;
    }

    gpio_bit_reset(GPIOA, GPIO_PIN_13);
}

int main(void)
{  
    /* setup default time values */
    current_time.hour=0;
    current_time.minute=0;
    current_time.second=0;

    /* initialize NIXIE tube drivers */
    init_nixie(NIXIE_IN14_1);
    init_nixie(NIXIE_IN14_2);

#if ENABLE_COM
    /* initialize the com */
    init_UART();
#endif

    /* initialize buttons */
    init_buttons();

#if ENABLE_COM
    /* UART interrupt configuration */
    nvic_irq_enable(USART0_IRQn, 0);
#endif

    /* check clock position */
    get_clk_position(&show_minutes);

    /* initialize RTC */
    init_RTC(current_time);

    for(ever)
    {
        reset_tube(NIXIE_IN14_1);
        reset_tube(NIXIE_IN14_2);

#if ENABLE_COM
        check_for_new_timeValues();
#endif

        rtc_current_time_get(&current_time);
        display_time(&current_time, show_minutes);
    }
}

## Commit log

2025-02-07 migrated nixie_clock repository from GitLab to GitHub.
    [IN14_1.kicad_sch, IN14_2.kicad_sch, Nixie_Module.kicad_pcb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]
2025-02-07 Restructured entire repository to increase usability and define fundamental structure of the project.
    [IN14_1.kicad_sch, IN14_2.kicad_sch, Nixie_Module.kicad_pcb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]
2025-02-07 identical to the backup folder, deleted the redundant KiCAD project .
2025-10-27 fixed minute and hour switch relative to the boolean indicator.
    [BTN_nixie.c]
2025-10-29 removed 24h digit display bug. Additionally fixed bcd conversion bug and reduced unused variables from the software implementation.
    [BTN_nixie.c, main.c]
2025-11-09 added mirror layout support for sockets on the back of the pcb.
2025-11-12 minor bug fixes to correctly display the timeValues and correct transmission.
    [BTN_nixie.c, IN14_nixie.c, UART_com.c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]
2025-11-15 removed redundant config_hour and config_minute variables from the implementation and fixed couple of bugs in the course of implementation.
    [BTN_nixie.c, IN14_nixie.c, UART_com.c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]
2025-11-16 restructured the UART configuration interface and and cleaned up the main.c file.
2025-11-16 renamed socket folder.
    [Nixie_Socket.scad, Nixie_Socket.stl]
2025-11-17 added Apache License to the hardware implementation.
    [Nixie_Socket.scad]
